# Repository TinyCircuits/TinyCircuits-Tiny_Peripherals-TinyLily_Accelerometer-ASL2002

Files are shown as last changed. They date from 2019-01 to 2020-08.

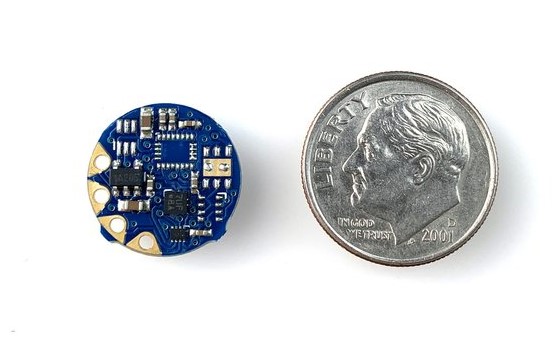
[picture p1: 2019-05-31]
images/ASL2002-Tutorial-Image-01.jpg

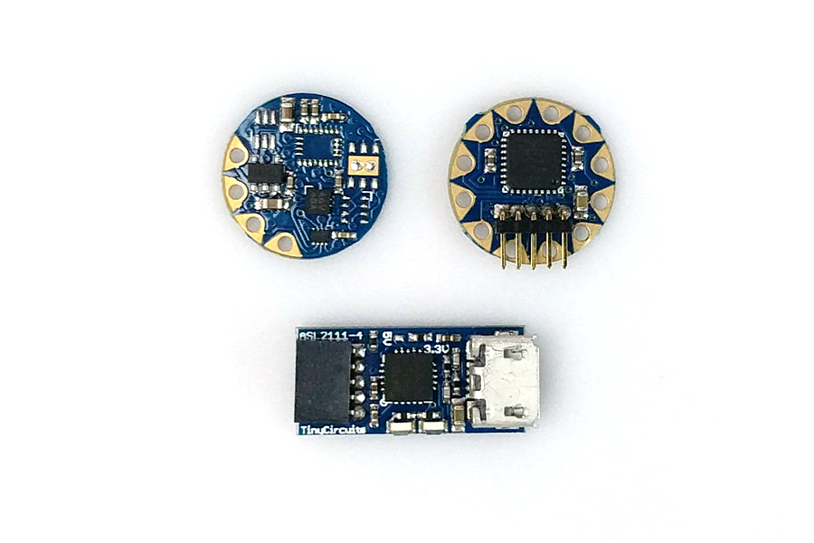
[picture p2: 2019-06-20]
images/ASL2002-Tutorial-Image-03.jpg

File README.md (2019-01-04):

# TinyCircuits Tiny Peripherals TinyLily Accelerometer
# ASL1003 Rev1

The design files are located under design_files/ for the TinyCircuits ASL1003 Rev 1 PCB.  This is a Tiny peripheral board that has options for different sensors to be populated.

Format is in Cadsoft Eagle format - Eagle version 6.2 was used for the original design.

For more infomation on this, check out the product page at TinyCircuits.com: https://tinycircuits.com/collections/tinylily/products/tinylily-accelerometer

# License:

Design by TinyCircuits.
All design files are released under the Creative Commons Attribution Share-Alike 3.0 License, see the following link for details: http://creativecommons.org/licenses/by-sa/3.0

All text above must be included in any redistribution or derived design

This project uses designs and concepts developed as part of the Arduino project and the LilyPad project.  The TinyCircuits design files themselves (schematics, PCB and libraries) are not directly derived from these works' design files and have been created new, however the concepts and basic architecture behind the TinyDuino and TinyLily products are derived and we thank the hard work of the organizations below for their contributions to open-source hardware:
  
Original Arduino Uno Design by Team Arduino

LilyPad Arduino Design by Leah Buechley and Sparkfun Electronics

Please support the open-source hardware community

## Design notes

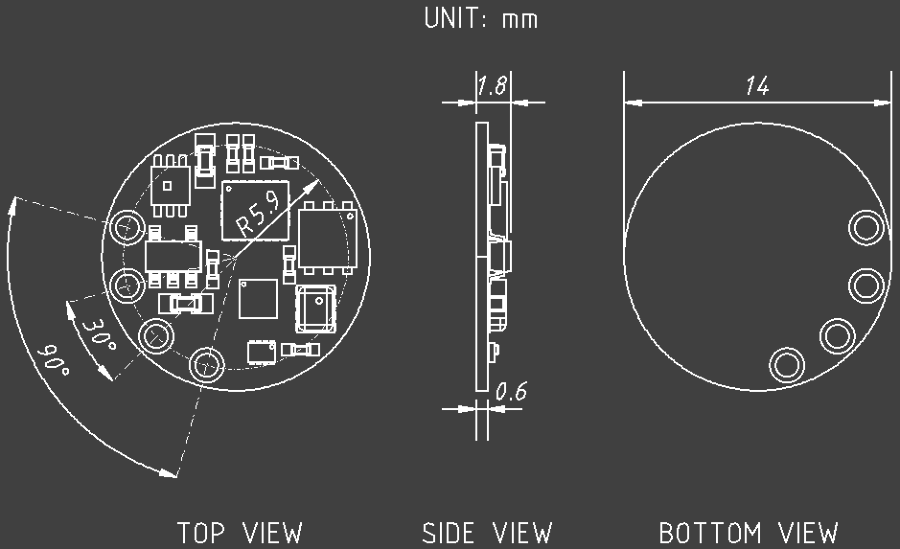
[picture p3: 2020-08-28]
cad/TinyLily_ACCELEROMETER_ASL2002_REV1-DETAILED_DRAWING_COMPACT-PNG.png

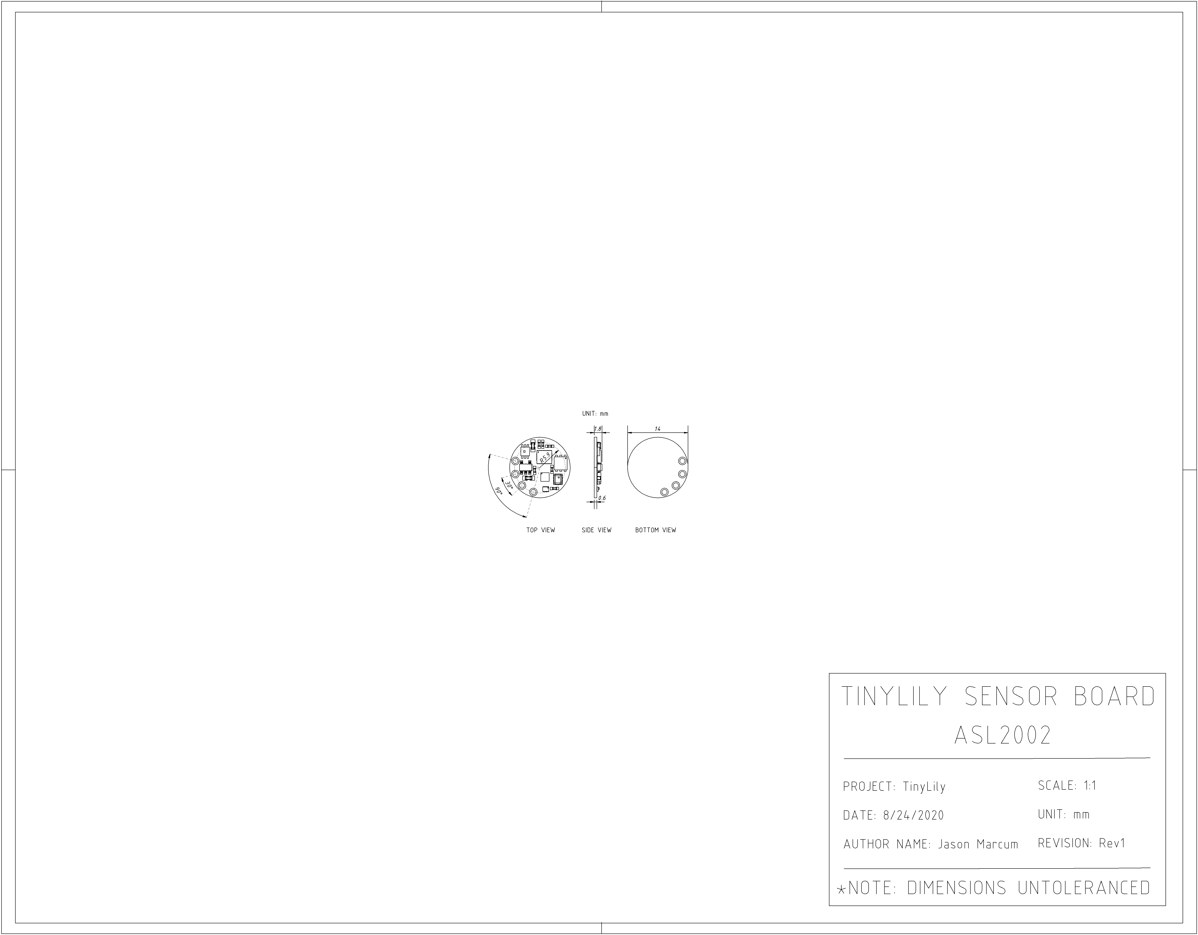
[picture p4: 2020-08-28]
cad/TinyLily_ACCELEROMETER_ASL2002_REV1-DETAILED_DRAWING-PNG.png

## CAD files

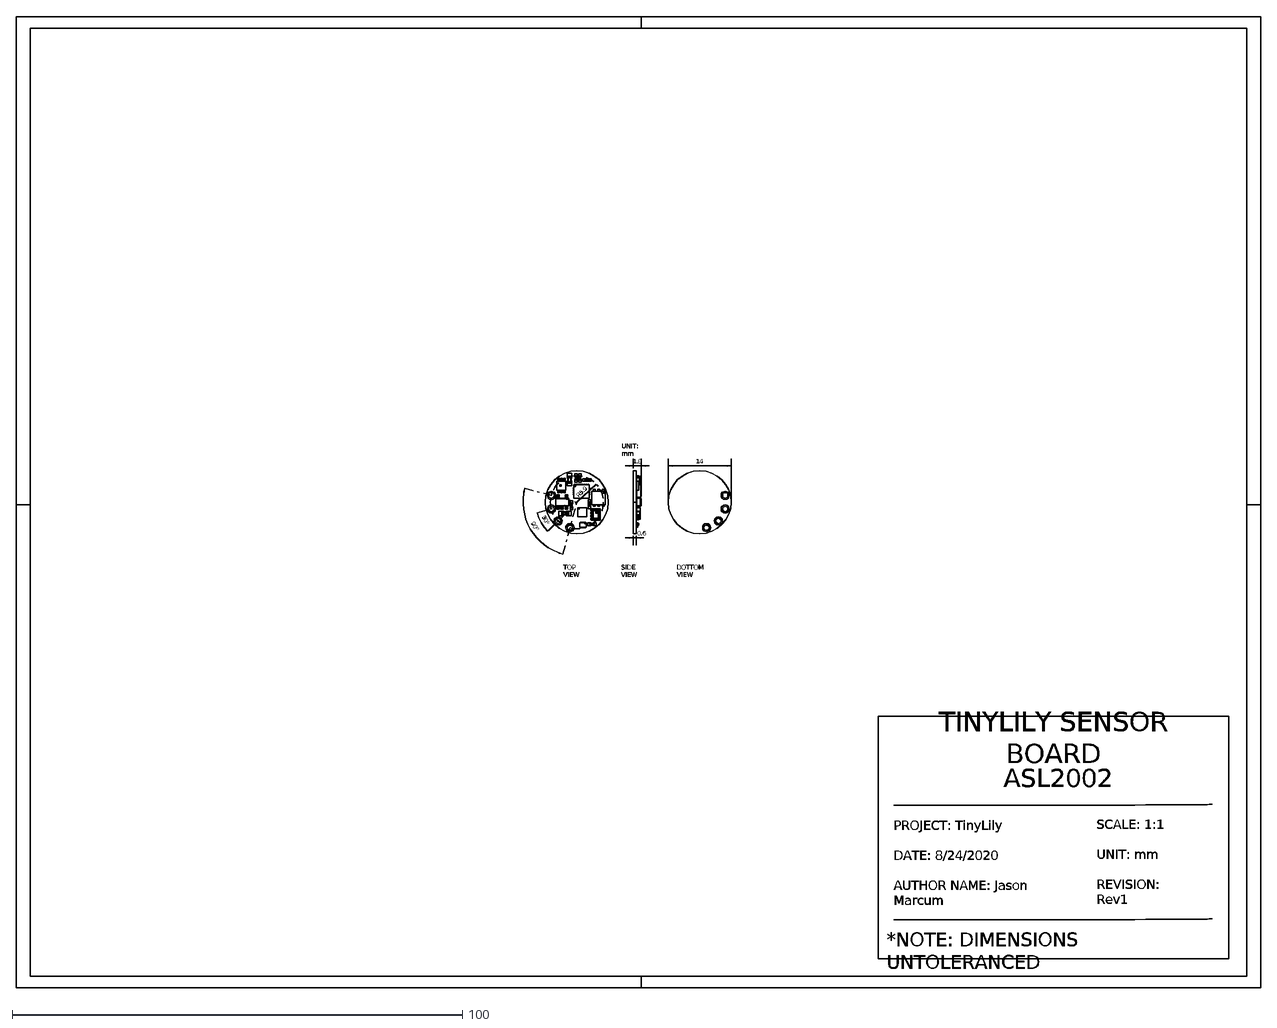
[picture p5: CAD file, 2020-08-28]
cad/TinyLily_ACCELEROMETER_ASL2002_REV1-DETAILED_DRAWING-DXF.dxf
*NOTE: DIMENSIONS UNTOLERANCED
SCALE: 1:1 UNIT: mm REVISION: Rev1
TOP VIEW
BOTTOM VIEW
SIDE VIEW
R5.9
90°
30°
1.8
0.6
14
UNIT: mm
TINYLILY SENSOR BOARD
ASL2002
PROJECT: TinyLily DATE: 8/24/2020 AUTHOR NAME: Jason Marcum

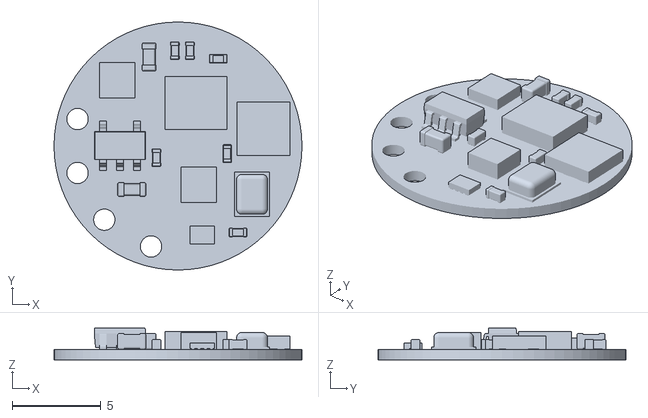
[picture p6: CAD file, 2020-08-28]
cad/TinyLily_ACCELEROMETER_ASL2002_REV1-STL.stl
14.0 x 14.0 x 1.80

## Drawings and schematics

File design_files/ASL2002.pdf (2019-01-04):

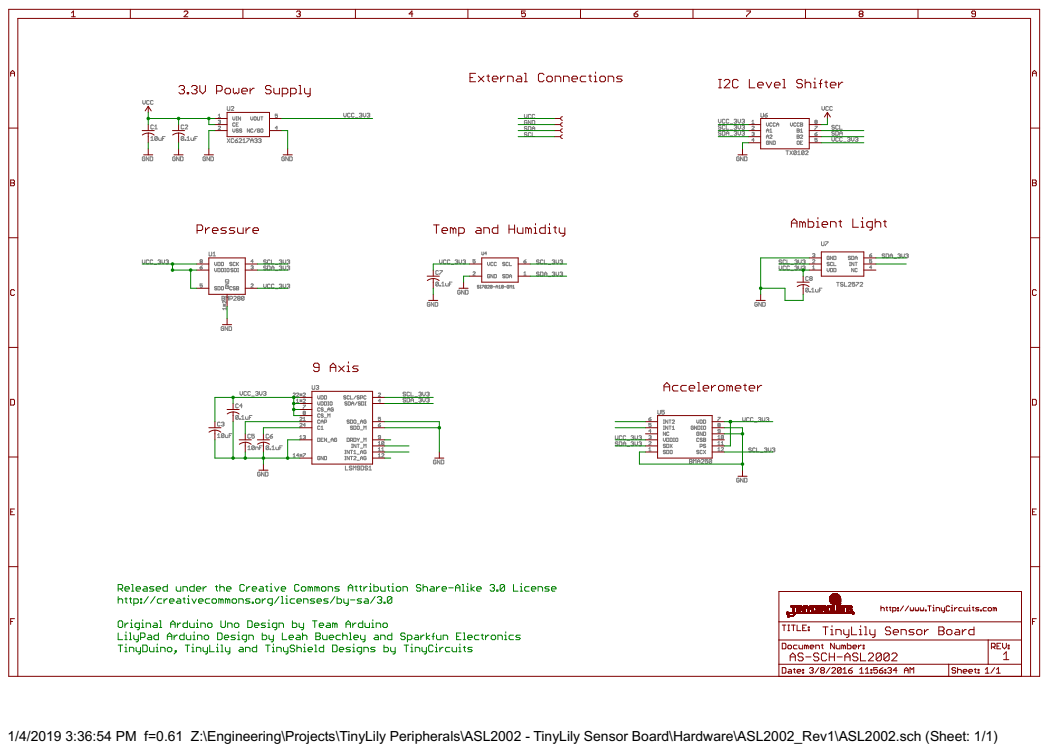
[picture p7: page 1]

1/4/2019 3:36:54 PM f=0.61 Z:\Engineering\Projects\TinyLily Peripherals\ASL2002 - TinyLily Sensor Board\Hardware\ASL2002_Rev1\ASL2002.sch (Sheet: 1/1)

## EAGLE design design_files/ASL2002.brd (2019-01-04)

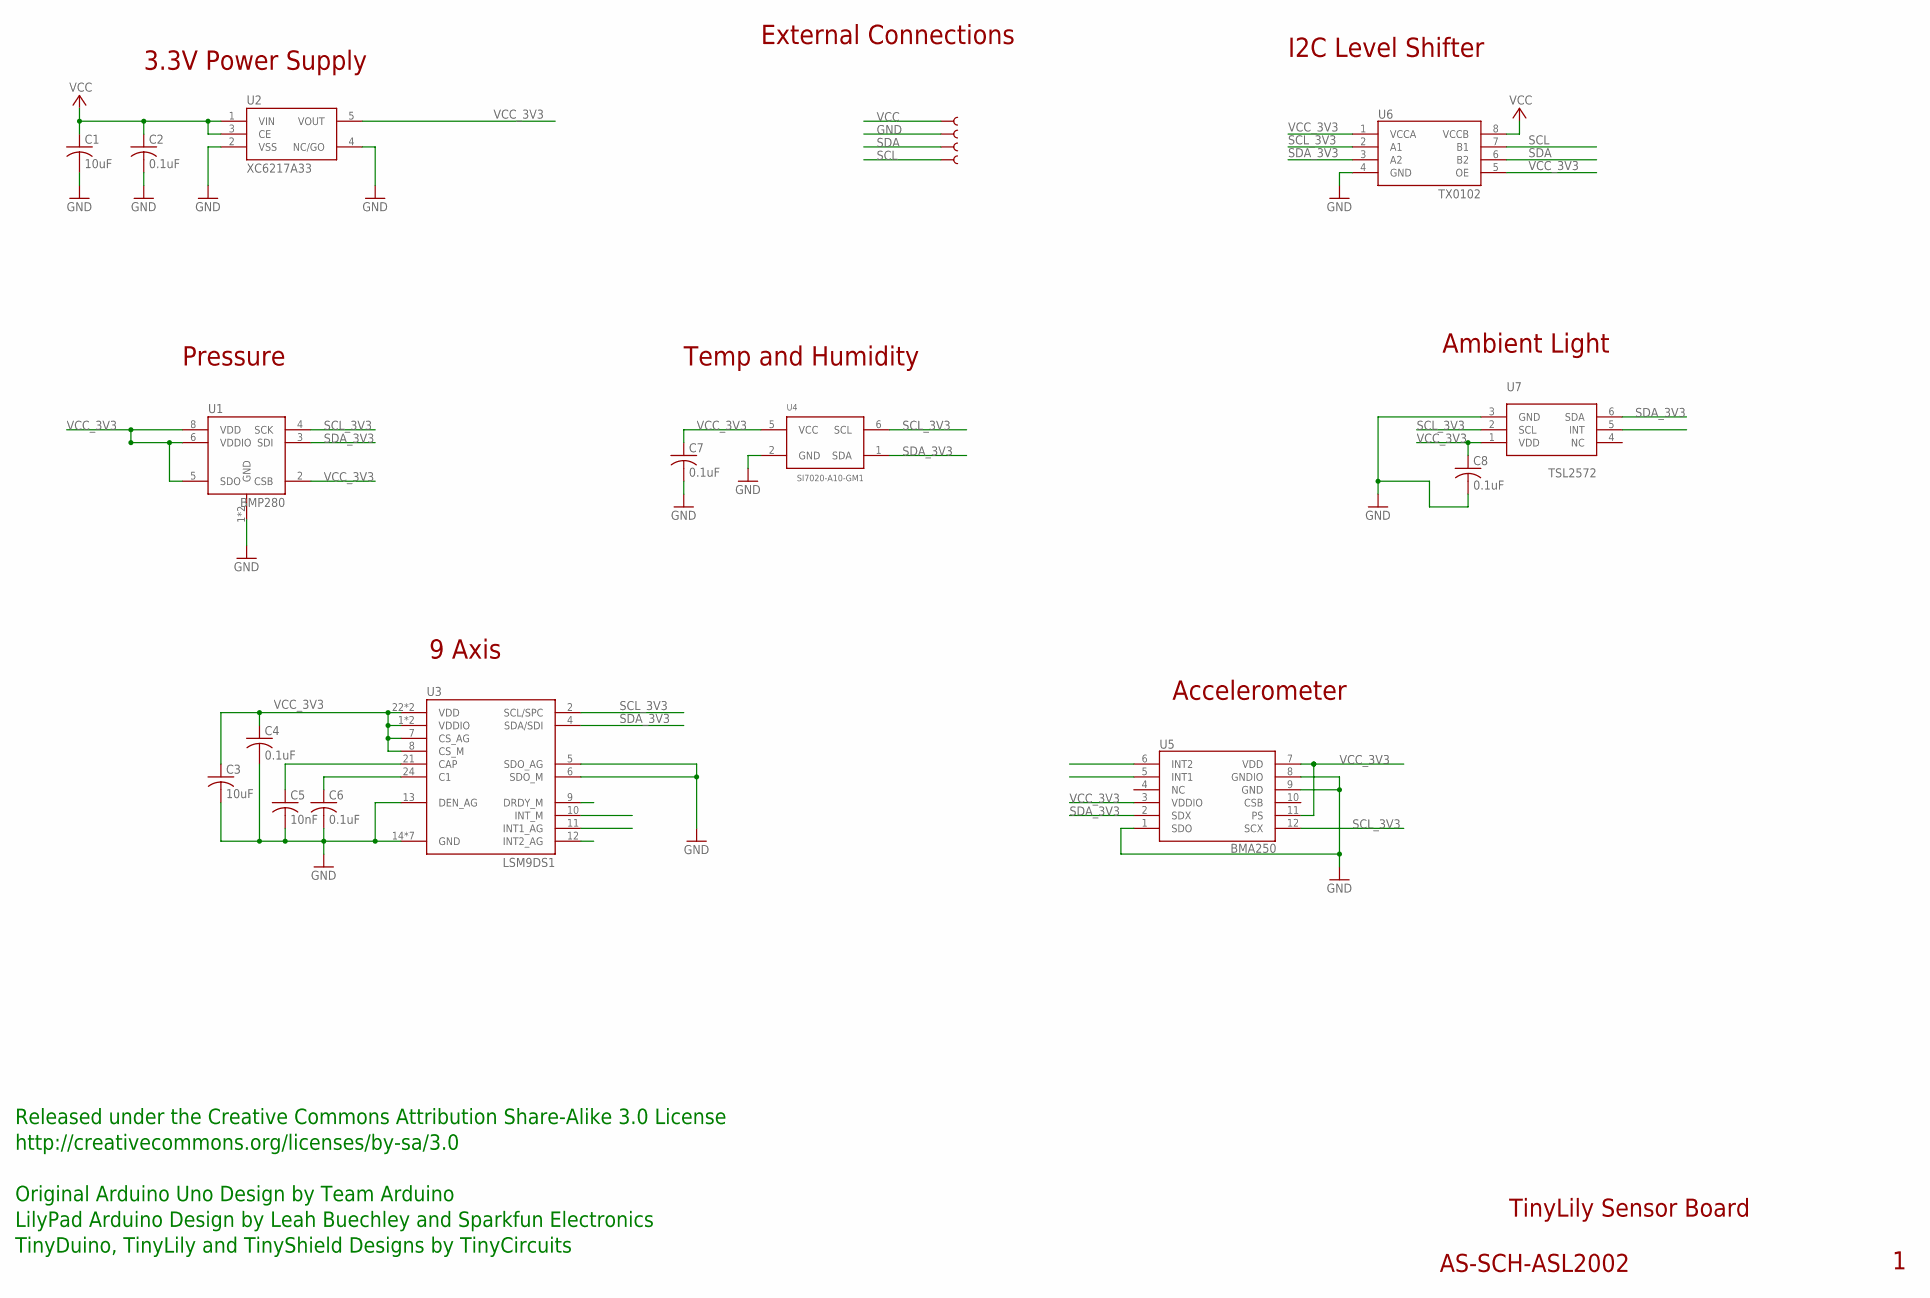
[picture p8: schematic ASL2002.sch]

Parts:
$1: SEWTAB; SEWTAP_TH
C1: 10uF; C0603
C2, C4, C7, C8: 0.1uF; C0402; PARTNO AS-ITM-00008
C3: 10uF; C0603; PARTNO AS-ITM-00002
C5: 10nF; C0402
C6: 0.1uF; C0402
U1: BMP280
U2: XC6217A33; SOT-25; PARTNO AS-ITM-00249
U3: LSM9DS1; LGA-24
U4: SI7020-A10-GM1; DFN6
U5: BMA250; 3-AXIS_ACCELEROMETER
U6: TX0102; DQE(R-PX2SON-N8)
U7: TSL2572
U$1, U$2, U$3: SEWTAB; SEWTAP_TH

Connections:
GND: C1.2, C2.2, C3.2, C4.2, C5.2, C6.2, C7.2, C8.2, U1.1 (GND), U1.7 (GND), U2.2 (VSS), U2.4 (NC/GO), U3.5 (SDO_AG), U3.6 (SDO_M), U3.13 (DEN_AG), U3.14 (GND), U3.15 (GND), U3.16 (GND), U3.17 (GND), U3.18 (GND), U3.19 (GND), U3.20 (GND), U4.2 (GND), U5.1 (SDO), U5.8 (GNDIO), U5.9 (GND), U6.4 (GND), U7.3 (GND), U$1.1
unnamed: C5.1, U3.21 (CAP)
unnamed: C6.1, U3.24 (C1)
SCL: U6.7 (B1), U$3.1
SCL_3V3: U1.4 (SCK), U3.2 (SCL/SPC), U4.6 (SCL), U5.12 (SCX), U6.2 (A1), U7.2 (SCL)
SDA: U6.6 (B2), U$2.1
SDA_3V3: U1.3 (SDI), U3.4 (SDA/SDI), U4.1 (SDA), U5.2 (SDX), U6.3 (A2), U7.6 (SDA)
VCC: $1.1, C1.1, C2.1, U2.1 (VIN), U2.3 (CE), U6.8 (VCCB)
VCC_3V3: C3.1, C4.1, C7.1, C8.1, U1.2 (CSB), U1.5 (SDO), U1.6 (VDDIO), U1.8 (VDD), U2.5 (VOUT), U3.1 (VDDIO), U3.3 (VDDIO), U3.7 (CS_AG), U3.8 (CS_M), U3.22 (VDD), U3.23 (VDD), U4.5 (VCC), U5.3 (VDDIO), U5.7 (VDD), U5.11 (PS), U6.1 (VCCA), U6.5 (OE), U7.1 (VDD)

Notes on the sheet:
TinyLily Sensor Board
AS-SCH-ASL2002
Released under the Creative Commons Attribution Share-Alike 3.0 License
http://creativecommons.org/licenses/by-sa/3.0
LilyPad Arduino Design by Leah Buechley and Sparkfun Electronics
TinyDuino, TinyLily and TinyShield Designs by TinyCircuits
Original Arduino Uno Design by Team Arduino
External Connections
3.3V Power Supply
I2C Level Shifter
9 Axis
Pressure
Temp and Humidity
Ambient Light
Accelerometer

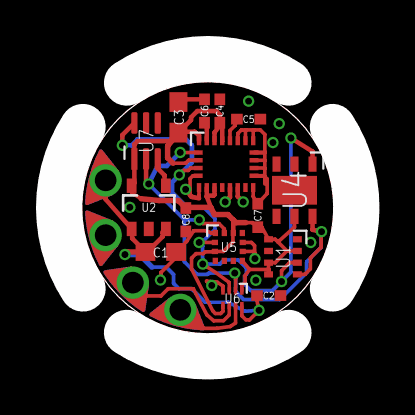
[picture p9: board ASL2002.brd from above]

Board: 2 copper layers, 14.0 x 14.0 mm, 20 parts (0 on the bottom side), 9 nets.

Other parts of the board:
U$6: DOCFIELD-TINYCIRCUITS-PCB

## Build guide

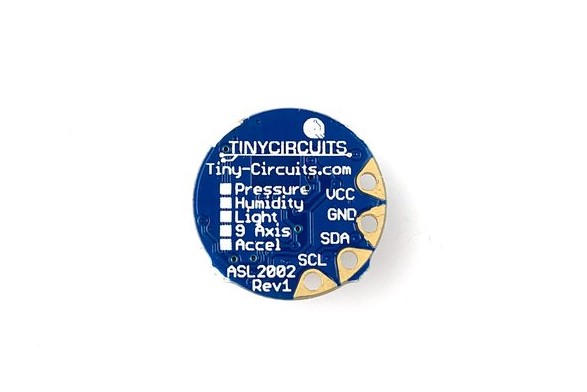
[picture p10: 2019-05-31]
images/ASL2002-Tutorial-Image-02.jpg

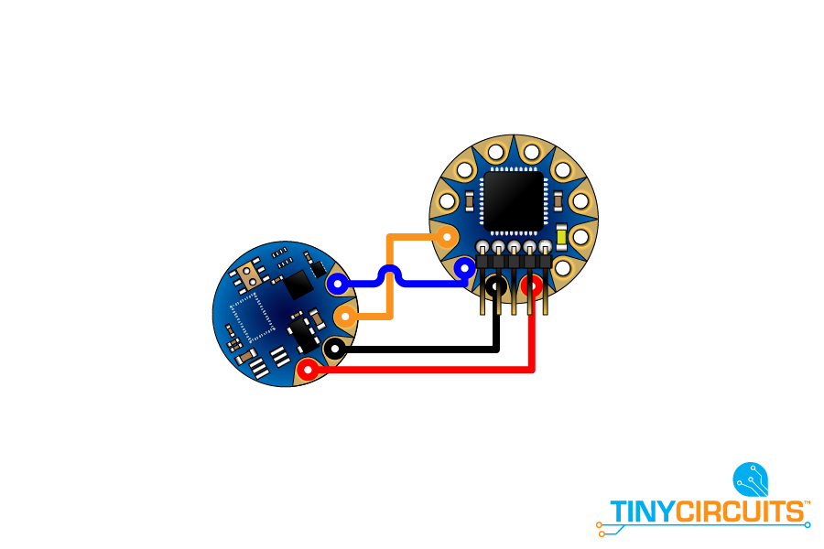
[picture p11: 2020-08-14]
images/ASL2002-Tutorial-Image-04.png

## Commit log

2019-01-04 update format
    [ASL2002.brd, ASL2002.sch]
2020-08-28 Add CAD data
    [TinyLily_ACCELEROMETER_ASL2002_REV1-DETAILED_DRAWING-DXF.dxf, TinyLily_ACCELEROMETER_ASL2002_REV1-STL.stl]
